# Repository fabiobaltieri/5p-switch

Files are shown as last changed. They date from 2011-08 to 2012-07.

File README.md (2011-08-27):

Five Port Managed Ethernet Switch
=================================

This project is a five port managed switch based on a Micrel KSZ8995M and an
Atmel ATMega168 microcontroller.

License
-------

This program is free software: you can redistribute it and/or modify
it under the terms of the GNU General Public License as published by
the Free Software Foundation, either version 3 of the License, or
(at your option) any later version.

Contents
--------

    COPYING     text version of the GPL
    README      this file
    firmware/   source directory for firmware files
    hardware/   source directory for the hardware design files

Firmware
--------

Building requires an avr-gcc toolchain, in the firmware/ directory, to build
run:

    make

Flashing the firmware on the device requires avrdude and a compatible hardware
programmer. Default configuration is stored at the beginning of the Makefile.
To program with the default configuration, run:

    make load

Fuses can be configured running:

    make fuse 

Hardware
--------

All hardware files (schematic, layout and libraries) are in CadSoft Eagle
format.

The switch can be configured in unmanaged mode by not shorting any jumper.

To configure the switch in SPI slave mode, PS[1:0] have to be set to 10, so
just short the pins 1 and 2 of SJ2.

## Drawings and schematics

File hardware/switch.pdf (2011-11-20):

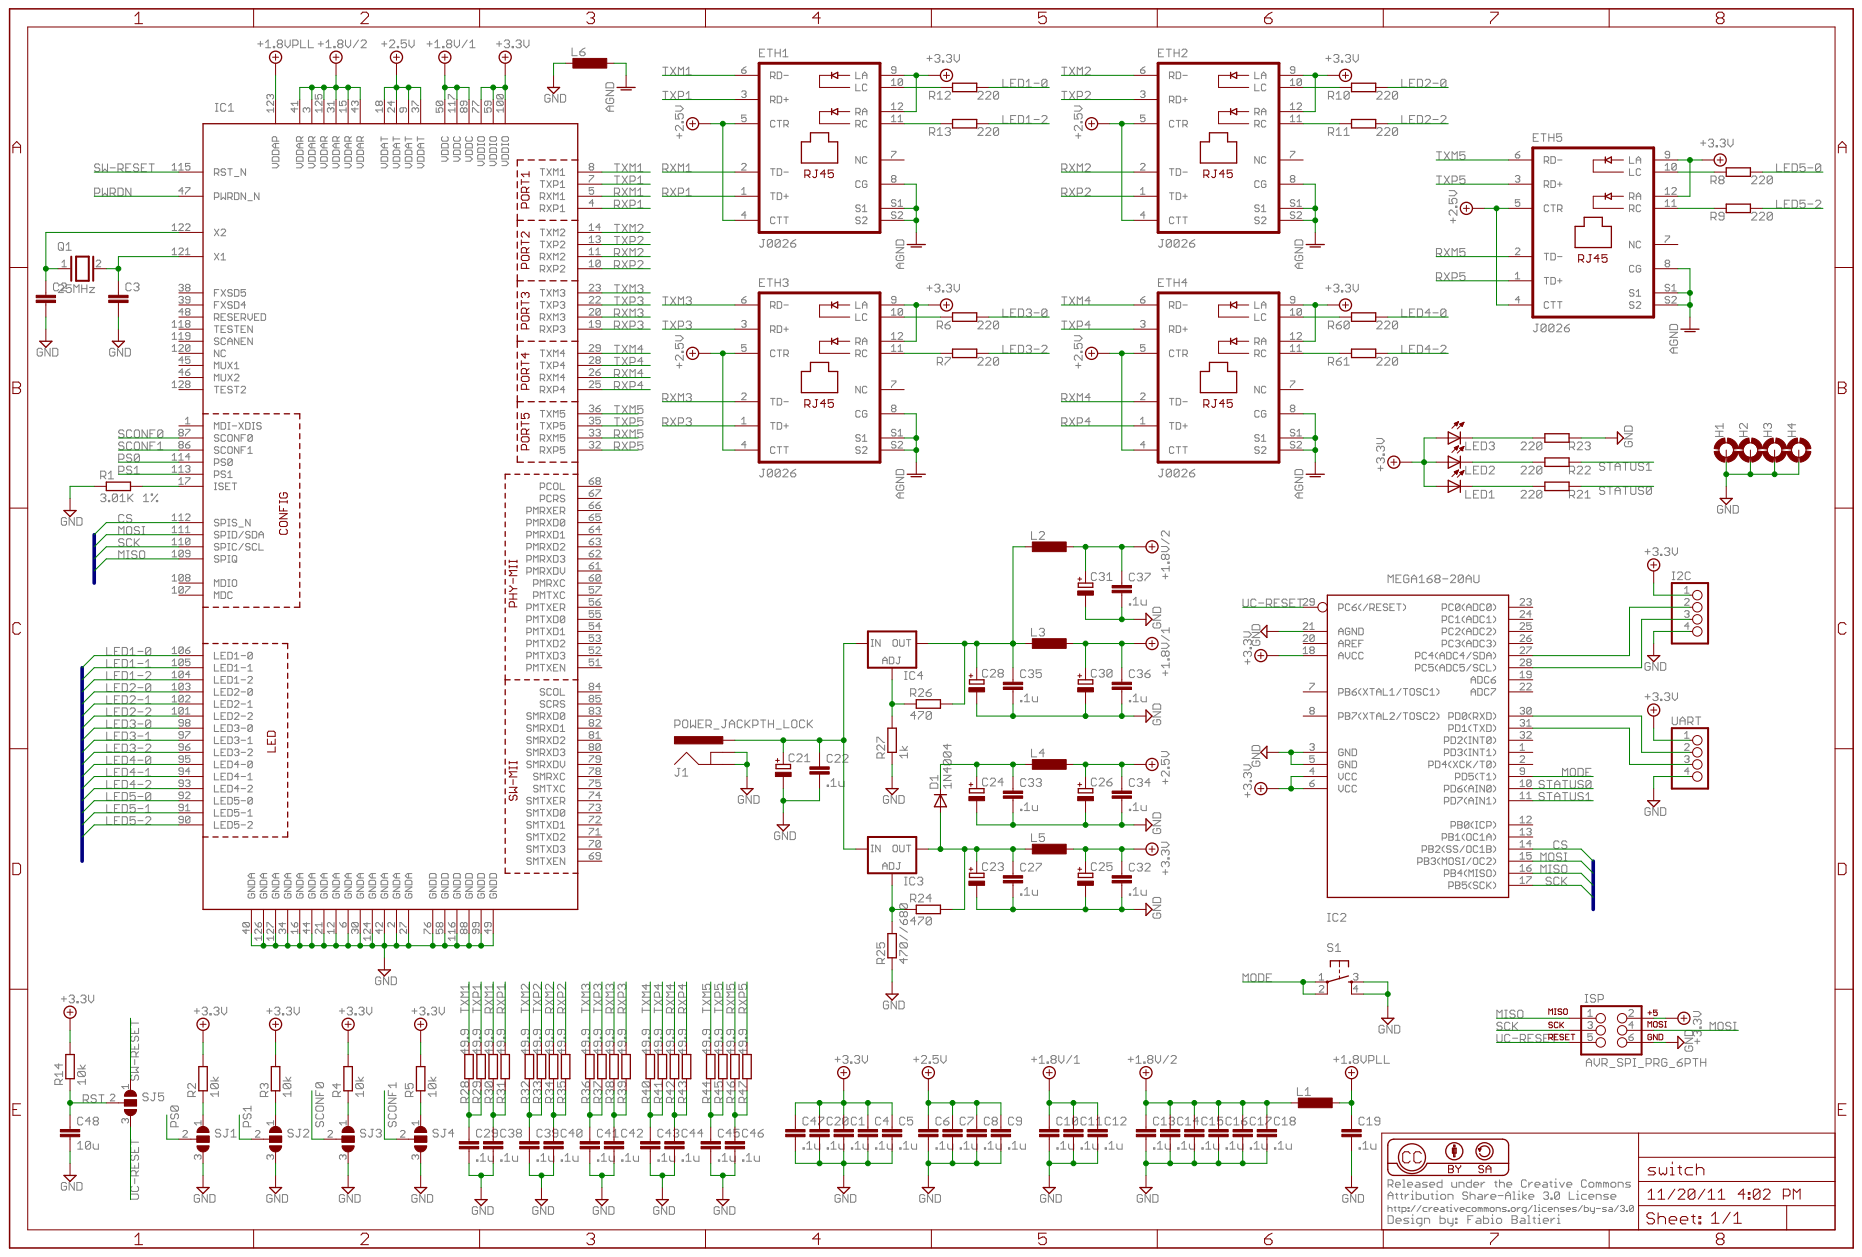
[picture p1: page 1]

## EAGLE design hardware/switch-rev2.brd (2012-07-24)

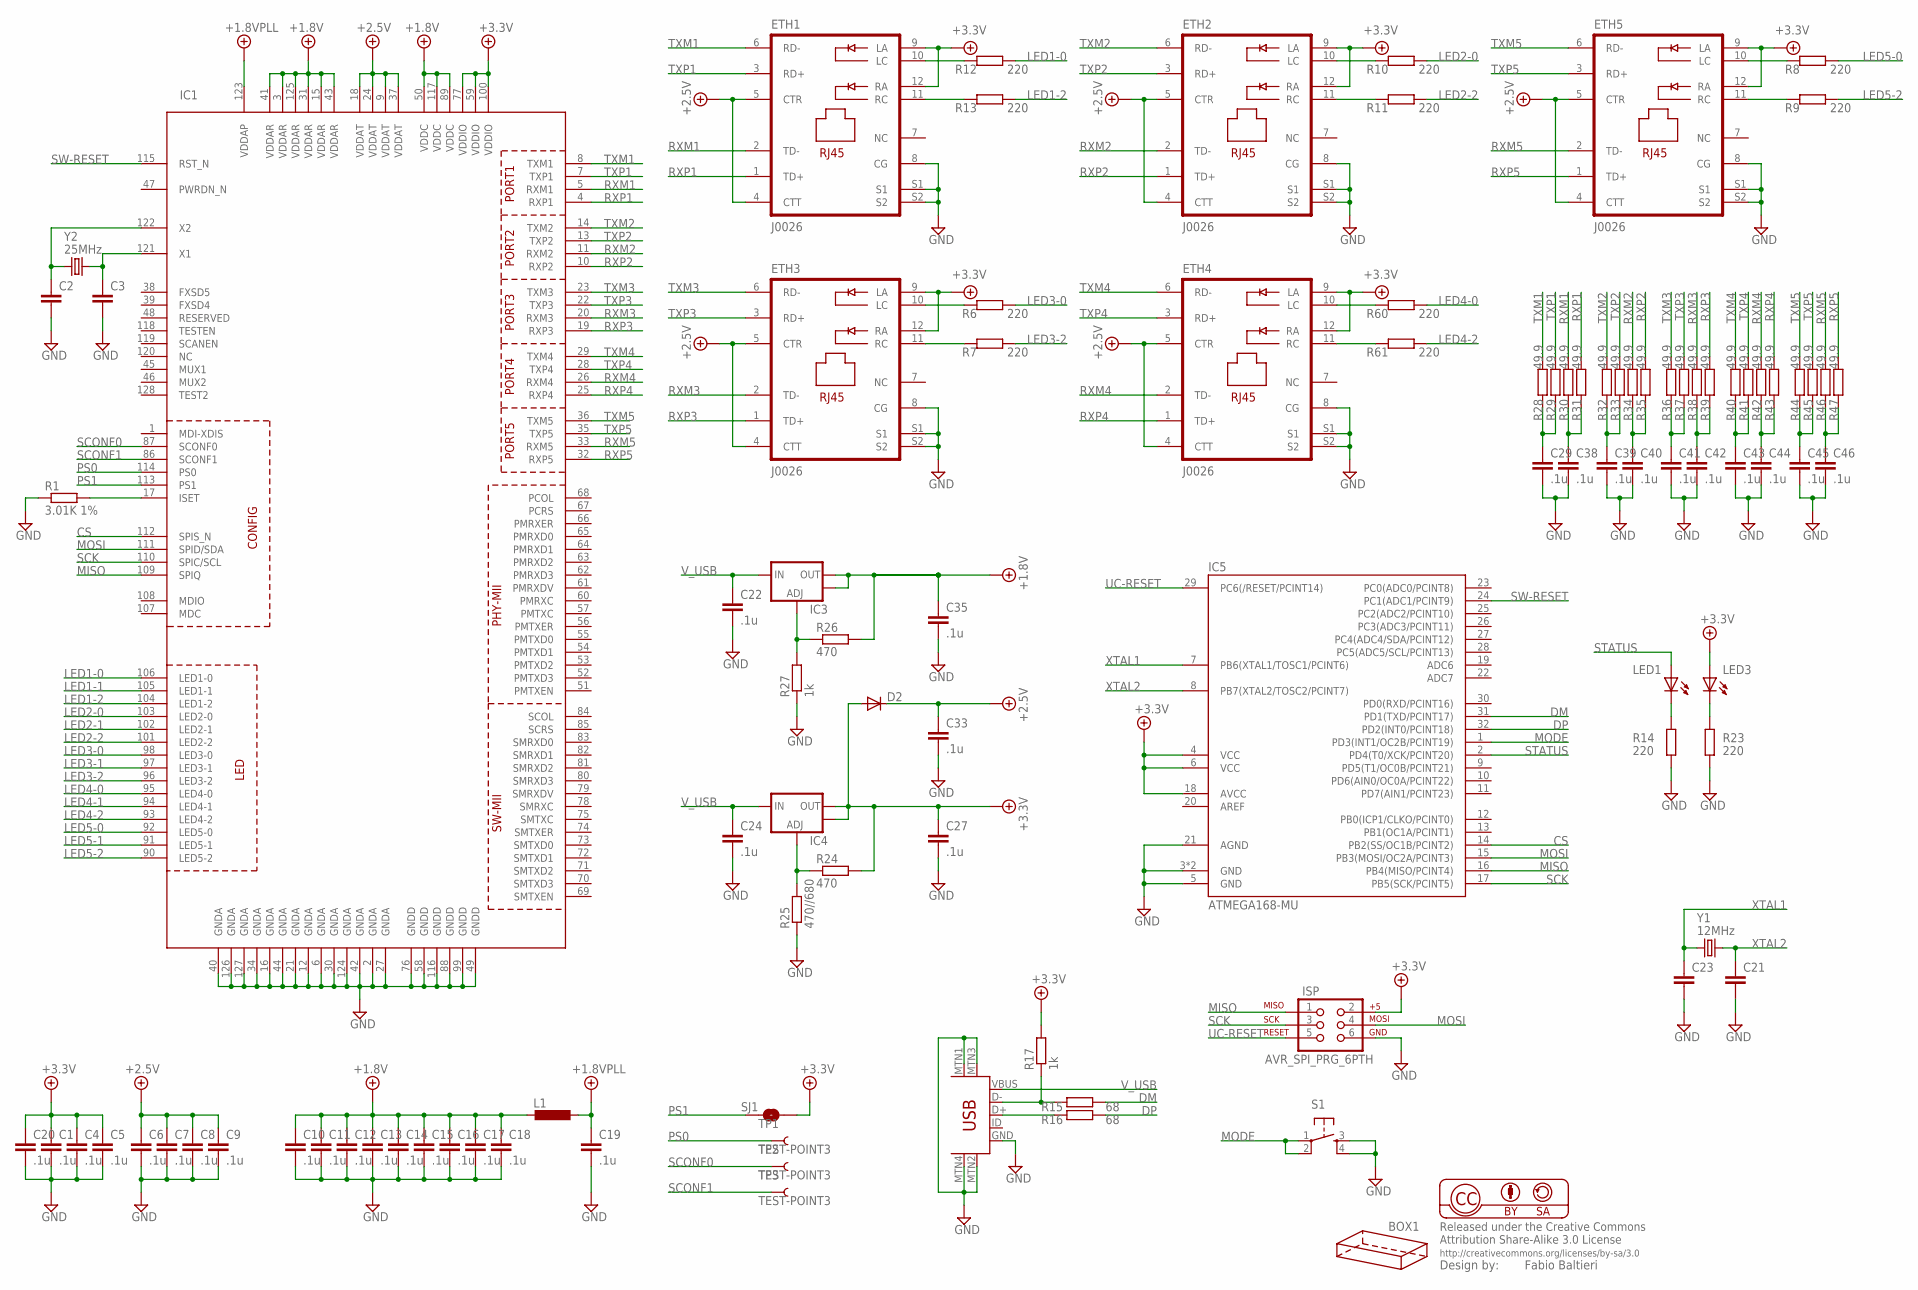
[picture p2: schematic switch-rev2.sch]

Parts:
BOX1: HAMMOND-BOX-XXA; 1591XXA
C1, C4, C5, C6, C7, C8, C9, C10, C11, C12, C13, C14, C15, C16, C17, C18, C19, C20, C22, C24, C27, C29, C33, C35, C38, C39, C40, C41, C42, C43, C44, C45, C46: .1u; C0805
C2, C3, C21, C23: C-EUC0805; C0805
D2: DIODE-SMB; SMB
ETH1, ETH2, ETH3, ETH4, ETH5: J0026; PJ-J0
IC1: KS8995MA; PQFP128L
IC3, IC4: V_REG_LM1117SOT223; SOT223
IC5: ATMEGA168-MU; MLF32-TH
ISP: AVR_SPI_PRG_6PTH; 2X3
L1: L-EUL2012C; L2012C
LED1, LED3: LEDCHIPLED_0603; CHIPLED_0603
R1: 3.01K 1%; R0603
R6, R7, R8, R9, R10, R11, R12, R13, R14, R23, R60, R61: 220; R0603
R15, R16: 68; R0603
R17, R27: 1k; R0603
R24, R26: 470; R0603
R25: 470//680; R0603
R28, R29, R30, R31, R32, R33, R34, R35, R36, R37, R38, R39, R40, R41, R42, R43, R44, R45, R46, R47: 49.9; R0603
S1: TAC_SWITCHSMD; TACTILE_SWITCH_SMD
SJ1: SOLDERJUMPERTRACE; SJ_2S-TRACE
TP1, TP2, TP3: TEST-POINT3; PAD.03X.03
U$1: USB-MINIB-5PIN; USB-MINIB
Y1: 12MHz; CRYSTAL-SMD-5X3
Y2: 25MHz; CRYSTAL-SMD-5X3

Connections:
+5V: C1.1, C4.1, C5.1, C20.1, C27.1, D2.A, ETH1.9 (LA), ETH1.12 (RA), ETH2.9 (LA), ETH2.12 (RA), ETH3.9 (LA), ETH3.12 (RA), ETH4.9 (LA), ETH4.12 (RA), ETH5.9 (LA), ETH5.12 (RA), IC1.59 (VDDIO), IC1.77 (VDDIO), IC1.100 (VDDIO), IC4.2 (OUT), IC4.4 (OUT), IC5.4 (VCC), IC5.6 (VCC), IC5.18 (AVCC), ISP.2, LED3.A, R17.2, R24.2, SJ1.2
+5V/1: C6.1, C7.1, C8.1, C9.1, C33.1, D2.C, ETH1.4 (CTT), ETH1.5 (CTR), ETH2.4 (CTT), ETH2.5 (CTR), ETH3.4 (CTT), ETH3.5 (CTR), ETH4.4 (CTT), ETH4.5 (CTR), ETH5.4 (CTT), ETH5.5 (CTR), IC1.9 (VDDAT), IC1.18 (VDDAT), IC1.24 (VDDAT), IC1.37 (VDDAT)
+5V/2: C10.1, C11.1, C12.1, C13.1, C14.1, C15.1, C16.1, C17.1, C18.1, C35.1, IC1.3 (VDDAR), IC1.15 (VDDAR), IC1.31 (VDDAR), IC1.41 (VDDAR), IC1.43 (VDDAR), IC1.50 (VDDC), IC1.89 (VDDC), IC1.117 (VDDC), IC1.125 (VDDAR), IC3.2 (OUT), IC3.4 (OUT), L1.2, R26.2
+5V/4: C19.1, IC1.123 (VDDAP), L1.1
CS: IC1.112 (SPIS_N), IC5.14 (PB2(SS/OC1B/PCINT2))
DM: IC5.31 (PD1(TXD/PCINT17)), R15.1
DP: IC5.32 (PD2(INT0/PCINT18)), R16.1
GND: C1.2, C2.2, C3.2, C4.2, C5.2, C6.2, C7.2, C8.2, C9.2, C10.2, C11.2, C12.2, C13.2, C14.2, C15.2, C16.2, C17.2, C18.2, C19.2, C20.2, C21.2, C22.2, C23.2, C24.2, C27.2, C29.2, C33.2, C35.2, C38.2, C39.2, C40.2, C41.2, C42.2, C43.2, C44.2, C45.2, C46.2, ETH1.8 (CG), ETH1.S1, ETH1.S2, ETH2.8 (CG), ETH2.S1, ETH2.S2, ETH3.8 (CG), ETH3.S1, ETH3.S2, ETH4.8 (CG), ETH4.S1, ETH4.S2, ETH5.8 (CG), ETH5.S1, ETH5.S2, IC1.2 (GNDA), IC1.6 (GNDA), IC1.12 (GNDA), IC1.16 (GNDA), IC1.21 (GNDA), IC1.27 (GNDA), IC1.30 (GNDA), IC1.34 (GNDA), IC1.40 (GNDA), IC1.42 (GNDA), IC1.44 (GNDA), IC1.49 (GNDD), IC1.58 (GNDD), IC1.76 (GNDD), IC1.88 (GNDD), IC1.99 (GNDD), IC1.116 (GNDD), IC1.124 (GNDA), IC1.126 (GNDA), IC1.127 (GNDA), IC5.3 (GND), IC5.5 (GND), IC5.21 (AGND), IC5.TH (GND), ISP.6, R1.1, R14.1, R23.1, R25.1, R27.1, S1.3, S1.4, U$1.GND, U$1.MTN1 (MTN2), U$1.MTN2 (MTN3), U$1.MTN3 (MTN1), U$1.MTN4
LED1-0: IC1.106 (LED1-0), R12.1
LED1-1: IC1.105 (LED1-1)
LED1-2: IC1.104 (LED1-2), R13.1
LED2-0: IC1.103 (LED2-0), R10.1
LED2-1: IC1.102 (LED2-1)
LED2-2: IC1.101 (LED2-2), R11.1
LED3-0: IC1.98 (LED3-0), R6.1
LED3-1: IC1.97 (LED3-1)
LED3-2: IC1.96 (LED3-2), R7.1
LED4-0: IC1.95 (LED4-0), R60.1
LED4-1: IC1.94 (LED4-1)
LED4-2: IC1.93 (LED4-2), R61.1
LED5-0: IC1.92 (LED5-0), R8.1
LED5-1: IC1.91 (LED5-1)
LED5-2: IC1.90 (LED5-2), R9.1
MISO: IC1.109 (SPIQ), IC5.16 (PB4(MISO/PCINT4)), ISP.1
MODE: IC5.1 (PD3(INT1/OC2B/PCINT19)), S1.1, S1.2
MOSI: IC1.111 (SPID/SDA), IC5.15 (PB3(MOSI/OC2A/PCINT3)), ISP.4
unnamed: IC1.17 (ISET), R1.2
unnamed: C2.1, IC1.122 (X2), Y2.1
unnamed: C3.1, IC1.121 (X1), Y2.3 (2)
unnamed: ETH1.11 (RC), R13.2
unnamed: ETH3.10 (LC), R6.2
unnamed: ETH3.11 (RC), R7.2
unnamed: ETH5.10 (LC), R8.2
unnamed: ETH5.11 (RC), R9.2
unnamed: ETH2.10 (LC), R10.2
unnamed: ETH1.10 (LC), R12.2
unnamed: ETH2.11 (RC), R11.2
unnamed: LED1.C, R14.2
unnamed: R15.2, R17.1, U$1.D-
unnamed: R16.2, U$1.D+
unnamed: LED3.C, R23.2
unnamed: IC4.1 (ADJ), R24.1, R25.2
unnamed: IC3.1 (ADJ), R26.1, R27.2
unnamed: C29.1, R28.1, R29.1
unnamed: C38.1, R30.1, R31.1
unnamed: C39.1, R32.1, R33.1
unnamed: C40.1, R34.1, R35.1
unnamed: C41.1, R36.1, R37.1
unnamed: C42.1, R38.1, R39.1
unnamed: C43.1, R40.1, R41.1
unnamed: C44.1, R42.1, R43.1
unnamed: C45.1, R44.1, R45.1
unnamed: C46.1, R46.1, R47.1
unnamed: ETH4.10 (LC), R60.2
unnamed: ETH4.11 (RC), R61.2
PS0: IC1.114 (PS0), TP1.P$1
PS1: IC1.113 (PS1), SJ1.1
RXM1: ETH1.2 (TD-), IC1.5 (RXM1), R30.2
RXM2: ETH2.2 (TD-), IC1.11 (RXM2), R34.2
RXM3: ETH3.2 (TD-), IC1.20 (RXM3), R38.2
RXM4: ETH4.2 (TD-), IC1.26 (RXM4), R42.2
RXM5: ETH5.2 (TD-), IC1.33 (RXM5), R46.2
RXP1: ETH1.1 (TD+), IC1.4 (RXP1), R31.2
RXP2: ETH2.1 (TD+), IC1.10 (RXP2), R35.2
RXP3: ETH3.1 (TD+), IC1.19 (RXP3), R39.2
RXP4: ETH4.1 (TD+), IC1.25 (RXP4), R43.2
RXP5: ETH5.1 (TD+), IC1.32 (RXP5), R47.2
SCK: IC1.110 (SPIC/SCL), IC5.17 (PB5(SCK/PCINT5)), ISP.3
SCONF0: IC1.87 (SCONF0), TP2.P$1
SCONF1: IC1.86 (SCONF1), TP3.P$1
STATUS: IC5.2 (PD4(T0/XCK/PCINT20)), LED1.A
SW-RESET: IC1.115 (RST_N), IC5.24 (PC1(ADC1/PCINT9))
TXM1: ETH1.6 (RD-), IC1.8 (TXM1), R28.2
TXM2: ETH2.6 (RD-), IC1.14 (TXM2), R32.2
TXM3: ETH3.6 (RD-), IC1.23 (TXM3), R36.2
TXM4: ETH4.6 (RD-), IC1.29 (TXM4), R40.2
TXM5: ETH5.6 (RD-), IC1.36 (TXM5), R44.2
TXP1: ETH1.3 (RD+), IC1.7 (TXP1), R29.2
TXP2: ETH2.3 (RD+), IC1.13 (TXP2), R33.2
TXP3: ETH3.3 (RD+), IC1.22 (TXP3), R37.2
TXP4: ETH4.3 (RD+), IC1.28 (TXP4), R41.2
TXP5: ETH5.3 (RD+), IC1.35 (TXP5), R45.2
UC-RESET: IC5.29 (PC6(/RESET/PCINT14)), ISP.5
V_USB: C22.1, C24.1, IC3.3 (IN), IC4.3 (IN), U$1.VBUS
XTAL1: C23.1, IC5.7 (PB6(XTAL1/TOSC1/PCINT6)), Y1.1
XTAL2: C21.1, IC5.8 (PB7(XTAL2/TOSC2/PCINT7)), Y1.3 (2)

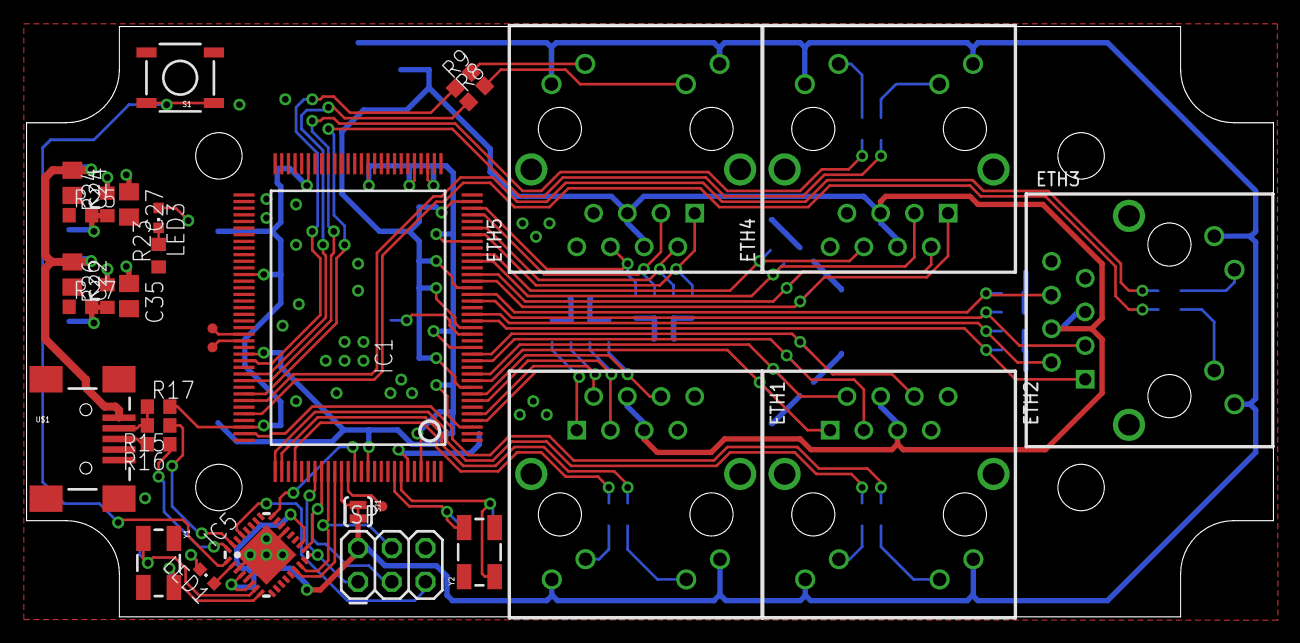
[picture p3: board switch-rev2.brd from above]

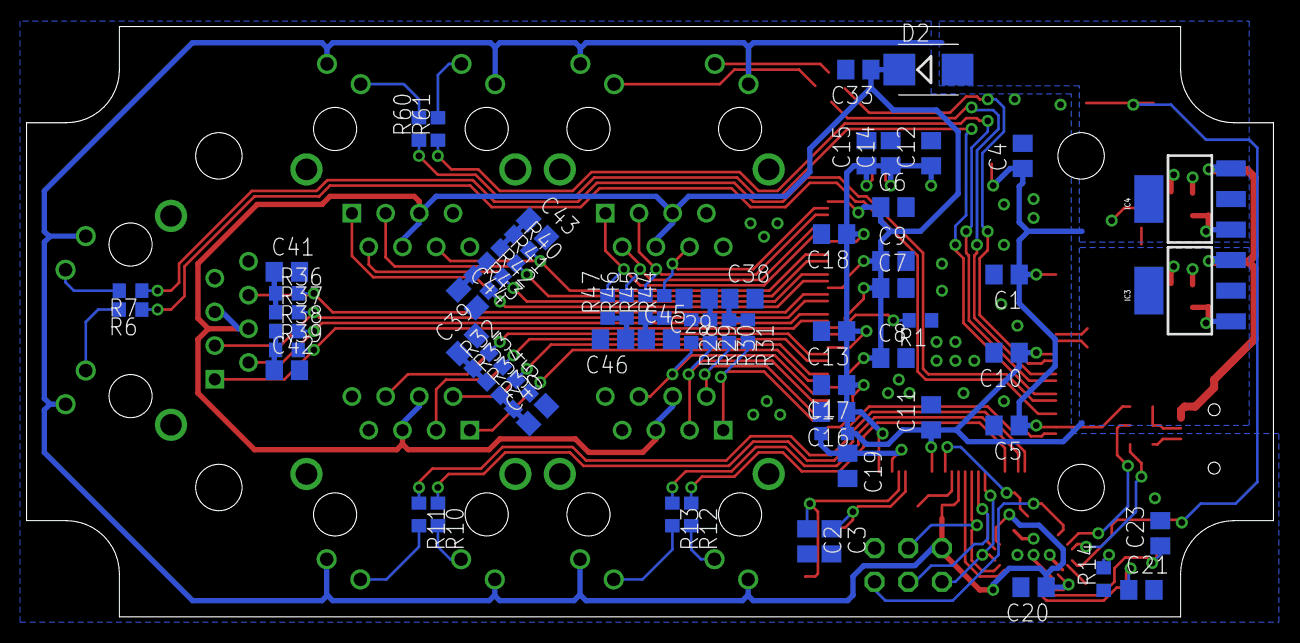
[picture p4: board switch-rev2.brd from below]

Board: 2 copper layers, 94.0 x 44.5 mm, 100 parts (67 on the bottom side), 81 nets.

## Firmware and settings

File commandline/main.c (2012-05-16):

#include <stdio.h>
#include <stdlib.h>
#include <string.h>
#include <stdint.h>
#include <unistd.h>
#include <fcntl.h>
#include <sys/stat.h>
#include <sys/types.h>
#include <endian.h>

#include <usb.h>

#include "opendevice.h"

#include "../firmware-usb/requests.h"

#define VENDOR  "www.fabiobaltieri.com"
#define PRODUCT "5p-switch"

#define N_PORTS 5

struct port_config {
        uint8_t ctrl[15];
        uint8_t status;
};

static void ksz_dump_port_status(usb_dev_handle *handle)
{
	struct port_config ports[N_PORTS];
	int ret;
	int i;

	ret = usb_control_msg(handle,
			      USB_TYPE_VENDOR | USB_RECIP_DEVICE |
			      USB_ENDPOINT_IN,
			      CUSTOM_RQ_GET_PORT_STATUS,
			      0, 0, (char *)ports, sizeof(ports), 1000);

	if (ret < 0) {
		printf("usb_control_msg: %s\n", usb_strerror());
		exit(1);
	}

	if (ret != sizeof(ports)) {
		printf("%s: short transfer\n", __func__);
		return;
	}

	for (i = 0; i < N_PORTS; i++)
		printf("port%d: <%s%s%s%s%s%s%s%s>\n", i,
		       ports[i].status & 0x80 ? "MDI" : "MDI-X",
		       ports[i].status & 0x40 ? ",AN" : "",
		       ports[i].status & 0x20 ? ",LINK" : "",
		       ports[i].status & 0x10 ? ",FLOW" : "",
		       ports[i].status & 0x08 ? ",100BT-FD" : "",
		       ports[i].status & 0x04 ? ",100BT-HD" : "",
		       ports[i].status & 0x02 ? ",10BT-FD" : "",
		       ports[i].status & 0x01 ? ",10BT-HD" : "");
}

static void ksz_dump_dm(usb_dev_handle *handle)
{
	int ret;
	int i;
	uint8_t buf[512];
	uint8_t *ptr;
	uint16_t offset;

	printf("port\tage\tfid\taddr\n");

	offset = 0;
	do {
		ret = usb_control_msg(handle,
				      USB_TYPE_VENDOR | USB_RECIP_DEVICE |
				      USB_ENDPOINT_IN,
				      CUSTOM_RQ_GET_DM,
				      0, offset, (char *)buf, sizeof(buf), 1000);

		if (ret < 0) {
			printf("usb_control_msg: %s\n", usb_strerror());
			exit(1);
		}

		ptr = buf;
		for (i = 0; i < ret / 8; i++) {
			printf("%d\t%d\t%d\t%02x:%02x:%02x:%02x:%02x:%02x\n",
			       (ptr[6] >> 4) & 0x07,
			       ptr[7] & 0x03,
			       ptr[6] & 0x0f,
			       ptr[5],
			       ptr[4],
			       ptr[3],
			       ptr[2],
			       ptr[1],
			       ptr[0]);
			ptr += 8;
		}

		offset += ret / 8;
	} while (ret == sizeof(buf));
}

static void ksz_dump_vlan(usb_dev_handle *handle)
{
	int ret;
	int i;
	uint8_t buf[16 * 4];
	uint8_t *ptr;

	ret = usb_control_msg(handle,
			      USB_TYPE_VENDOR | USB_RECIP_DEVICE |
			      USB_ENDPOINT_IN,
			      CUSTOM_RQ_GET_VLAN,
			      0, 0, (char *)buf, sizeof(buf), 1000);

	if (ret < 0) {
		printf("usb_control_msg: %s\n", usb_strerror());
		exit(1);
	}

	if (ret != sizeof(buf)) {
		printf("%s: short transfer\n", __func__);
		return;
	}

	printf("valid\tmember\tfid\tvid\n");

	ptr = buf;
	for (i = 0; i < ret / 4; i++) {
		printf("%d\t%x\t%d\t%d\n",
		       (ptr[2] >> 5) & 0x01,
		       (ptr[2] >> 0) & 0x1f,
		       (ptr[1] >> 4) & 0x0f,
		       (ptr[1] << 8 | ptr[0]) & 0x0fff);
		ptr += 4;
	}
}

static char *mib_names[32] = {
	"RxLoPriorityByte",
	"RxHiPriorityByte",
	"RxUndersizePkt",
	"RxFragments",
	"RxOversize",
	"RxJabbers",
	"RxSymbolError",
	"RxCRCerror",
	"RxAlignmentError",
	"RxControl8808Pkts",
	"RxPausePkts",
	"RxBroadcast",
	"RxMulticast",
	"RxUnicast",
	"Rx64Octets",
	"Rx65to127Octets",
	"Rx128to255Octets",
	"Rx256to511Octets",
	"Rx512to1023Octets",
	"Rx1024to1522Octets",
	"TxLoPriorityByte",
	"TxHiPriorityByte",
	"TxLateCollision",
	"TxPausePkts",
	"TxBroadcastPkts",
	"TxMulticastPkts",
	"TxUnicastPkts",
	"TxDeferred",
	"TxTotalCollision",
	"TxExcessiveCollision",
	"TxSingleCollision",
	"TxMultipleCollision",
};

static void ksz_dump_mib(usb_dev_handle *handle)
{
	int ret;
	int i, j;
	uint32_t buf[N_PORTS][32];
	uint32_t val;

	for (i = 0; i < N_PORTS; i++) {
		ret = usb_control_msg(handle,
				      USB_TYPE_VENDOR | USB_RECIP_DEVICE |
				      USB_ENDPOINT_IN,
				      CUSTOM_RQ_GET_MIB,
				      0, i, (char *)buf[i], sizeof(*buf), 1000);

		if (ret < 0) {
			printf("usb_control_msg: %s\n", usb_strerror());
			exit(1);
		}

		if (ret != sizeof(*buf)) {
			printf("%s: short transfer\n", __func__);
			return;
		}
	}

	printf("                           port0"
	       "       port1"
	       "       port2"
	       "       port3"
	       "       port4\n");
	for (j = 0; j < 32; j++) {
		printf("%20s", mib_names[j]);
		for (i = 0; i < N_PORTS; i++) {
			val = buf[i][j];
			printf(" %s%10d",
			       val & 0x80000000 ? "*" : " ",
			       val & 0x3fffffff);
		}
		printf("\n");
	}
}

static void send_reset(usb_dev_handle *handle)
{
	int ret;

	ret = usb_control_msg(handle,
			      USB_TYPE_VENDOR | USB_RECIP_DEVICE |
			      USB_ENDPOINT_IN,
			      CUSTOM_RQ_RESET,
			      0, 0, NULL, 0, 1000);

	if (ret < 0) {
		printf("usb_control_msg: %s\n", usb_strerror());
		exit(1);
	}
}

static void usage(char *name)
{
	fprintf(stderr, "Usage: %s -h\n", name);
	fprintf(stderr, "       %s -R\n", name);
	fprintf(stderr, "       %s [options]\n", name);
	fprintf(stderr, "options\n");
	fprintf(stderr, "  -h         this help\n");
	fprintf(stderr, "  -R         reset device\n");
	fprintf(stderr, "  -p         dump port status\n");
	fprintf(stderr, "  -m         dump mib tables\n");
	fprintf(stderr, "  -v         dump vlan tables\n");
	fprintf(stderr, "  -d         dump dynamic MAC table\n");
	fprintf(stderr, "  -a         dump all (default)\n");
	exit(1);
}

#define DUMP_PORTS	0x01
#define DUMP_MIB	0x02
#define DUMP_VLAN	0x04
#define DUMP_DM		0x08
#define DUMP_ALL	0xff

int main(int argc, char **argv)
{
	usb_dev_handle *handle = NULL;
	int opt;
	int reset = 0;
	int dump_flags = 0;

	usb_init();

	while ((opt = getopt(argc, argv, "hRpmvda")) != -1) {
		switch (opt) {
		case 'h':
			usage(argv[0]);
			break;
                case 'R':
                        reset = 1;
                        break;
                case 'p':
			dump_flags |= DUMP_PORTS;
                        break;
                case 'm':
			dump_flags |= DUMP_MIB;
                        break;
                case 'v':
			dump_flags |= DUMP_VLAN;
                        break;
                case 'd':
			dump_flags |= DUMP_DM;
                        break;
                case 'a':
			dump_flags |= DUMP_ALL;
                        break;
		default:
			usage(argv[0]);
		}
	}

	if (optind < argc)
		usage(argv[0]);

	if (usbOpenDevice(&handle, 0, VENDOR, 0, PRODUCT, NULL, NULL, NULL) != 0) {
		fprintf(stderr, "error: could not find USB device \"%s\"\n", PRODUCT);
		exit(1);
	}

	if (reset) {
		send_reset(handle);
		return 0;
	}

	if (!dump_flags)
		dump_flags = DUMP_ALL;

	if (dump_flags & DUMP_PORTS) {
		ksz_dump_port_status(handle);
		printf("\n");
	}
	if (dump_flags & DUMP_MIB) {
		ksz_dump_mib(handle);
		printf("\n");
	}
	if (dump_flags & DUMP_VLAN) {
		ksz_dump_vlan(handle);
		printf("\n");
	}
	if (dump_flags & DUMP_DM) {
		ksz_dump_dm(handle);
		printf("\n");
	}

	usb_close(handle);

	return 0;
}

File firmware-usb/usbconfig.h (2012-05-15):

/* Name: usbconfig.h
 * Project: V-USB, virtual USB port for Atmel's(r) AVR(r) microcontrollers
 * Author: Christian Starkjohann
 * Creation Date: 2005-04-01
 * Tabsize: 4
 * Copyright: (c) 2005 by OBJECTIVE DEVELOPMENT Software GmbH
 * License: GNU GPL v2 (see License.txt), GNU GPL v3 or proprietary (CommercialLicense.txt)
 * This Revision: $Id$
 */

#ifndef __usbconfig_h_included__
#define __usbconfig_h_included__

/*
General Description:
This file is an example configuration (with inline documentation) for the USB
driver. It configures V-USB for USB D+ connected to Port D bit 2 (which is
also hardware interrupt 0 on many devices) and USB D- to Port D bit 4. You may
wire the lines to any other port, as long as D+ is also wired to INT0 (or any
other hardware interrupt, as long as it is the highest level interrupt, see
section at the end of this file).
+ To create your own usbconfig.h file, copy this file to your project's
+ firmware source directory) and rename it to "usbconfig.h".
+ Then edit it accordingly.
*/

/* ---------------------------- Hardware Config ---------------------------- */

#define USB_CFG_IOPORTNAME      D
/* This is the port where the USB bus is connected. When you configure it to
 * "B", the registers PORTB, PINB and DDRB will be used.
 */
#define USB_CFG_DMINUS_BIT      0
/* This is the bit number in USB_CFG_IOPORT where the USB D- line is connected.
 * This may be any bit in the port.
 */
#define USB_CFG_DPLUS_BIT       1
/* This is the bit number in USB_CFG_IOPORT where the USB D+ line is connected.
 * This may be any bit in the port. Please note that D+ must also be connected
 * to interrupt pin INT0! [You can also use other interrupts, see section
 * "Optional MCU Description" below, or you can connect D- to the interrupt, as
 * it is required if you use the USB_COUNT_SOF feature. If you use D- for the
 * interrupt, the USB interrupt will also be triggered at Start-Of-Frame
 * markers every millisecond.]
 */
#define USB_CFG_CLOCK_KHZ       (F_CPU/1000)
/* Clock rate of the AVR in kHz. Legal values are 12000, 12800, 15000, 16000,
 * 16500, 18000 and 20000. The 12.8 MHz and 16.5 MHz versions of the code
 * require no crystal, they tolerate +/- 1% deviation from the nominal
 * frequency. All other rates require a precision of 2000 ppm and thus a
 * crystal!
 * Since F_CPU should be defined to your actual clock rate anyway, you should
 * not need to modify this setting.
 */
#define USB_CFG_CHECK_CRC       0
/* Define this to 1 if you want that the driver checks integrity of incoming
 * data packets (CRC checks). CRC checks cost quite a bit of code size and are
 * currently only available for 18 MHz crystal clock. You must choose
 * USB_CFG_CLOCK_KHZ = 18000 if you enable this option.
 */

/* ----------------------- Optional Hardware Config ------------------------ */

/* #define USB_CFG_PULLUP_IOPORTNAME   D */
/* If you connect the 1.5k pullup resistor from D- to a port pin instead of
 * V+, you can connect and disconnect the device from firmware by calling
 * the macros usbDeviceConnect() and usbDeviceDisconnect() (see usbdrv.h).
 * This constant defines the port on which the pullup resistor is connected.
 */
/* #define USB_CFG_PULLUP_BIT          4 */
/* This constant defines the bit number in USB_CFG_PULLUP_IOPORT (defined
 * above) where the 1.5k pullup resistor is connected. See description
 * above for details.
 */

/* --------------------------- Functional Range ---------------------------- */
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

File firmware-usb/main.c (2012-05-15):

#include <avr/io.h>
#include <avr/wdt.h>
#include <avr/interrupt.h>
#include <util/delay.h>

#include "usbdrv.h"

#include "requests.h"

#include "board.h"
#include "spi.h"
#include "ksz8995ma.h"

struct port_config {
	uint8_t ctrl[15];
	uint8_t status;
};

static uint8_t buf[512];

static void reset_cpu(void)
{
	wdt_disable();

	wdt_enable(WDTO_15MS);

	for (;;);
}

static uint16_t dump_mib(uint8_t port, uint8_t *buf, uint16_t size)
{
	uint16_t i;
	uint16_t addr;

	if (size < 32 * 4)
		return 0;

	for (i = 0; i < 32; i++) {
		addr = i + 0x20 * port;
		spi_write(IAC_RD | IAC_MIB | ((addr >> 8) & 0x03), IAC0);
		spi_write(addr & 0xff, IAC1);

		do {
			buf[3] = spi_read(IDR3);
		} while (!(buf[3] & 0x40));

		buf[2] = spi_read(IDR2);
		buf[1] = spi_read(IDR1);
		buf[0] = spi_read(IDR0);

		buf += 4;
	}

	return 32 * 4;
}

static uint16_t dump_vlan(uint8_t *buf, uint16_t size)
{
	uint16_t i;

	if (size < 16 * 4)
		return 0;

	for (i = 0; i < 16; i++) {
		spi_write(IAC_RD | IAC_VLAN | ((i >> 8) & 0x03), IAC0);
		spi_write(i & 0xff, IAC1);

		buf[3] = 0x00;
		buf[2] = spi_read(IDR2);
		buf[1] = spi_read(IDR1);
		buf[0] = spi_read(IDR0);

		buf += 4;
	}

	return 16 * 4;
}

static uint16_t dump_dm(uint16_t off, uint8_t *buf, uint16_t size)
{
	uint16_t count;
	uint16_t i;
	uint8_t data[2];

	/* get number of entries */
	spi_write(IAC_RD | IAC_DM | ((off >> 8) & 0x03), IAC0);
	spi_write((off & 0xff), IAC1);

	data[1] = spi_read(IDR8);
	data[0] = spi_read(IDR7);

	/* table empty */
	if (data[1] & 0x10)
		return 0;

	count = ((((data[1] << 8) | data[0]) >> 2) & 0x3ff) + 1;

	/* dump table */
	for (i = 0; i < size / 8; i++) {
		spi_write(IAC_RD | IAC_DM | ((off >> 8) & 0x03), IAC0);
		spi_write(off & 0xff, IAC1);

		do {
			buf[6] = spi_read(IDR6);
		} while (buf[6] & 0x80);

		buf[7] = spi_read(IDR7);
		buf[5] = spi_read(IDR5);
		buf[4] = spi_read(IDR4);
		buf[3] = spi_read(IDR3);
		buf[2] = spi_read(IDR2);
		buf[1] = spi_read(IDR1);
		buf[0] = spi_read(IDR0);

		buf += 8;
		off++;

		if (off > count)
			break;
	}

	return i * 8;
}

static uint8_t dump_port_status(uint8_t *buf, uint16_t size)
{
	struct port_config *pc;
	uint8_t i;

	if (size < sizeof(*pc) * 5)
		return 0;

	for (i = 0; i < 5; i++) {
		pc = (struct port_config *)(buf + sizeof(*pc) * i);

		pc->ctrl[0]  = spi_read(PxC0(i));
		pc->ctrl[1]  = spi_read(PxC1(i));
		pc->ctrl[2]  = spi_read(PxC2(i));
		pc->ctrl[3]  = spi_read(PxC3(i));
		pc->ctrl[4]  = spi_read(PxC4(i));
		pc->ctrl[5]  = spi_read(PxC5(i));
		pc->ctrl[6]  = spi_read(PxC6(i));
		pc->ctrl[7]  = spi_read(PxC7(i));
		pc->ctrl[8]  = spi_read(PxC8(i));
		pc->ctrl[9]  = spi_read(PxC9(i));
		pc->ctrl[10] = spi_read(PxC10(i));
		pc->ctrl[11] = spi_read(PxC11(i));
		pc->ctrl[12] = spi_read(PxC12(i));
		pc->ctrl[13] = spi_read(PxC13(i));
		pc->ctrl[14] = spi_read(PxC14(i));

		pc->status = spi_read(PxS0(i));
	}

	return sizeof(*pc) * 5;
}

usbMsgLen_t usbFunctionSetup(uint8_t data[8])
{
	struct usbRequest *rq = (void *)data;
	uint16_t ret;

	led_b_toggle();

	if ((rq->bmRequestType & USBRQ_RCPT_MASK) != USBRQ_RCPT_DEVICE &&
	    (rq->bmRequestType & USBRQ_TYPE_MASK) != USBRQ_TYPE_VENDOR)
		return 0;

	switch (rq->bRequest) {
	case CUSTOM_RQ_READ_REG:
		buf[0] = spi_read(rq->wIndex.bytes[0]);
		usbMsgPtr = buf;
		return 1;
	case CUSTOM_RQ_WRITE_REG:
		spi_write(rq->wValue.bytes[0], rq->wIndex.bytes[0]);
		return 0;
	case CUSTOM_RQ_GET_PORT_STATUS:
		ret = dump_port_status(buf, sizeof(buf));
		usbMsgPtr = buf;
		return ret;
	case CUSTOM_RQ_GET_DM:
		ret = dump_dm(rq->wIndex.word, buf, sizeof(buf));
		usbMsgPtr = buf;
		return ret;
	case CUSTOM_RQ_GET_VLAN:
		ret = dump_vlan(buf, sizeof(buf));
		usbMsgPtr = buf;
		return ret;
	case CUSTOM_RQ_GET_MIB:
		ret = dump_mib(rq->wIndex.bytes[0], buf, sizeof(buf));
		usbMsgPtr = buf;
		return ret;
	case CUSTOM_RQ_RESET:
		reset_cpu();
		break;
	}

	return 0;
}

int __attribute__((noreturn)) main(void)
{
	uint8_t i;

	spi_init();

	led_init();
	led_a_off();
	led_b_off();

	wdt_enable(WDTO_1S);

	usbInit();
	usbDeviceDisconnect();

	for (i = 0; i < 6; i++) {
		wdt_reset();

		led_a_toggle();
		led_b_toggle();

		_delay_ms(50);
	}

	/* start switch */
	spi_write(0x01, ID1);

	usbDeviceConnect();

	sei();
	for (;;) {
		wdt_reset();
		usbPoll();
	}
}

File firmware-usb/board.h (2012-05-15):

/* LEDs */

#define LED_A_PORT    PORTD
#define LED_A_DDR     DDRD
#define LED_A         PD6

#define LED_B_PORT    PORTD
#define LED_B_DDR     DDRD
#define LED_B         PD7

#define led_a_on()     LED_A_PORT &= ~_BV(LED_A);
#define led_a_off()    LED_A_PORT |=  _BV(LED_A);
#define led_a_toggle() LED_A_PORT ^=  _BV(LED_A);

#define led_b_on()     LED_B_PORT &= ~_BV(LED_B);
#define led_b_off()    LED_B_PORT |=  _BV(LED_B);
#define led_b_toggle() LED_B_PORT ^=  _BV(LED_B);

#define led_init()				\
	do {					\
		LED_A_DDR |= _BV(LED_A);	\
		LED_B_DDR |= _BV(LED_B);	\
	} while (0);

/* SPI */

#define SPI_DDR  DDRB
#define SPI_PORT PORTB
#define SPI_SCK  PB5
#define SPI_MISO PB4
#define SPI_MOSI PB3
#define SPI_CS   PB2

#define spi_cs_h() SPI_PORT |=  _BV(SPI_CS)
#define spi_cs_l() SPI_PORT &= ~_BV(SPI_CS)

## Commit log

2011-08-18 5p-switch: initial import
2011-08-18 hardware: initial import
    [switch.brd, switch.sch]
2011-08-18 leds.c: removed wrong file insertion
2011-08-18 Makefile: added fuse target
2011-08-18 hw: fixed value of cap in reset circuit
    [switch.brd, switch.sch]
2011-08-18 hw: changed microcontroller part number
    [switch.brd, switch.sch]
2011-08-18 README: changed switch part number
2011-09-05 hardware: added schematic in pdf version
2011-11-20 hardware: add CC BY-SA license
    [switch.brd, switch.sch]
2012-05-15 bootloader: config for 5p-switch
2012-05-15 firmware-usb: fix led config
    [board.h]
2012-05-15 fw-usb: add led blink hello
2012-05-15 fw-usb: fix usb descriptors
    [usbconfig.h]
2012-05-15 fw-usb: add spi functions
2012-05-15 fw-usb: initial start switch
2012-05-15 fw-usb: spi: minor fixes, revers spi_write arguments
    [spi.c]
2012-05-15 fw-usb: fix dump_dm list
    [main.c]
2012-05-15 usb-fw: fix bug in dump_dm
    [main.c]
2012-05-15 cmdline: add print mib functionality
2012-05-16 fw-usb: disable spi 2X mode
    ks8995ma max SPI speed is 5MHz
2012-07-21 hw: add rev2
    [switch.brd, switch.sch]
2012-07-21 hw: move rev2 to the hardware directory
    [switch-rev2.brd, switch-rev2.sch]
2012-07-21 fw-usb: add missing files
    [commands.c]
2012-07-23 hw: rev2: progress save
    todo: fix QFN spacing
    [switch-rev2.brd, switch-rev2.sch]
2012-07-24 hw: rev2: change atmega QFN package
    [switch-rev2.brd, switch-rev2.sch]

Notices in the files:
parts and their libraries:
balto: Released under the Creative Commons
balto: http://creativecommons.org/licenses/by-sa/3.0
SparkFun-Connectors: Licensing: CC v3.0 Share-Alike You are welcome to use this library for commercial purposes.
